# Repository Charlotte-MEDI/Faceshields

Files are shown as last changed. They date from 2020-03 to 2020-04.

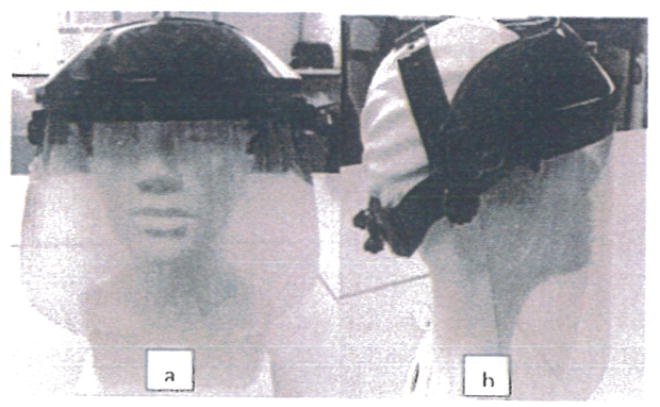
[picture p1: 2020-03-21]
research/cap_facemask.png

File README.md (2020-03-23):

# Faceshields
This repository is to keep track of novel designs of face mask for medical professional to use in critical times

At this time these files are not meant to be mass produced in anyway. As of right now, this is for prototyping different designs.

# March 22nd Print
We are currently printing the Face Shield and can be found in the PrusaFaceShield file.

# Resources:
Prusa Face Shield

https://blog.prusaprinters.org/from-design-to-mass-3d-printing-of-medical-shields-in-three-days/

# Other Designs to think about (May be easier to print?):
 https://www.scmp.com/news/hong-kong/health-environment/article/3052135/polytechnic-university-lab-3d-printing-face
 
 https://www.coxhealth.com/innovation/

# Working Fusion Models:  
-Live Link Prusa Bottom Reinforcement (original, for .5mm thick material) https://a360.co/2UbwLO5  
-Live Link Prusa Bottom Reinforcement (for 1.5mm thick material) https://a360.co/2QEyNnK  
-Believe this one should be a spot on replica, easy to alter the underlying sketches and file if needed  
-Live Link Prusa RC2  https://a360.co/3beMKk8  
-More straight lines in this model, much easier to sketch. Haven't test any prints, but model seems to be correct.  
-Live Link Prusa RC1  https://a360.co/2QAGLOJ

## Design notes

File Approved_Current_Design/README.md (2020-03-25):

# Help us print face shields - The Guide

### What can I do?

We'd love everyone to help!  If you have a 3d Printer, you can print this part:

[Download the 3d Part to Print](https://github.com/Charlotte-MEDI/Faceshields/blob/master/Approved_Current_Design/rc2_headband.stl)  

[Source File](https://www.prusaprinters.org/prints/26474-prusa-rc2-no-elastic-required-secure-with-rope-web)  

### Printer Settings

We want to ensure the printed part is both strong and flexible, our testing shows best results when the part is printed with **100% infill**.  

*Doesn't 100% infill take longer?*  Yes.  Faster, Better, Cheaper... When it comes to protecting our precious medical resources, the medical professionals, our first priority is the best protection.

### How can I package the parts

We want to ensure the printed parts are of the highest quality and does no harm.  

Clean all parts with alcohol (70% or better)
Mark the part with the date, material type (PETG or PLA) and then 
Don't touch the part with your bear hands
	We recommend using alcohol cleaned pliers to handle parts.
	You can use gloves, however, this can be costly.
Place the part in the bag to dry.
Seal the bag once the part is dry.

### Drop Off Locations?

Charlotte Latin FabLab

UNCC

### Additional Notes
These are the original designs from Prusa.  
As of now, these is the most tested, reliable design.  
If you are looking for something to print right away, these are the files for you.  
-The RC2 shield should be printed if your machine is capable.  
-The RC1 shield should by printed if your machine is too small to fit the RC2.  
-The bottom_reinforcement file should fit on any machine.  
-You should include a bottom reinforcement with every headband for a complete kit (minus the clear plastic part)

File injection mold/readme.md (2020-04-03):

This contains all of the design files for the injection molded face shields.

We want to help as many people produce face shields as possible so we’re making all of our files open source and available to everyone.

We started with the Prusa RC2 design and modified it to be injection molding friendly. With the help of Caro-Polymers, we designed a new bottom support that would accommodate PETG sheets of various thicknesses instead of being limited to only 0.02″ thick PETG.

Our design has been validated by doctors and other Health Care Workers in Charlotte, NC using the following materials to manufacture the face shields:

Following materials are used in this design: </br>
Injection molding: FDA approved Polypropylene </br>
PETG sheet: 0.02″ thick PETG (Our feedback from HCWs recommended 0.02″ thick)

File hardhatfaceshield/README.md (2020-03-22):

This face shield was developed by In Hong Yang and Dr. Park at UNC Charlotte.

Made a prototype of a face mask using projector transparency film, ratchet suspension, and hard hat.     
It took 2 minutes to make the prototype.   See the pictures attached.   Parts were glued together.   

https://www.mcmaster.com/5387t78  
Link:  Ratchet Suspension for Vented Hard Hat& Hard Hat with Rain-Trough Brim

https://www.mcmaster.com/5387t78  
Link:  Ratchet Suspension for Vented Hard Hat& Hard Hat with Rain-Trough Brim

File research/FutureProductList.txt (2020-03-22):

valves for ventelators
swabs
Near N95 mask

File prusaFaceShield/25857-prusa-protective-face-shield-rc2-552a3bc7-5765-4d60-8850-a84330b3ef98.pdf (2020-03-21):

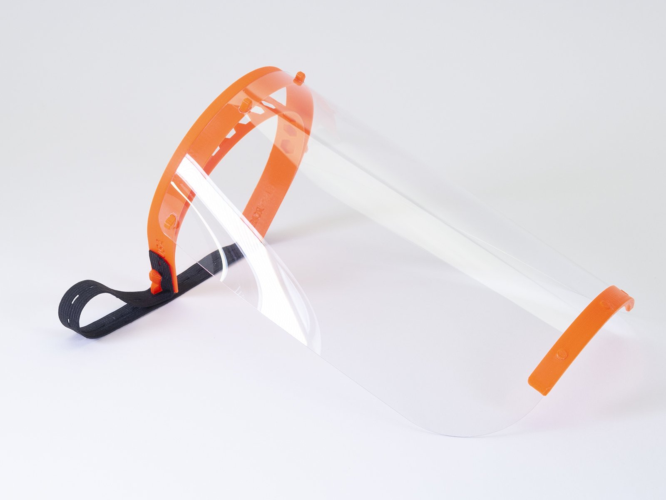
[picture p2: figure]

## Summary

A prototype face shield that we developed. In three days, we went through dozens of prototypes and two verifications with the Czech Ministry of Health.

Version RC2 Changes from RC1:

Increased wall thickness (slightly stiffer and more durable)
Inner wall from 1.5 mm to 2 mm
Outer wall from 2 mm to 2.5 mm
The headband is no longer printed compressed - Lower pressure on the temple
The visor was moved further away from the forehead - This allows a better fit over bigger respirators and protective goggles
The printed part now has an extension for the visor (the visor curves less than the headband).

For now, both RC1 and RC2 versions are relevant. RC1 lets you fit more printed parts on a single print bed. However, if maximum yield isn’t the priority, RC2 provides slightly better protection and is more comfortable to

Prusa Research (https://www.prusaprinters.org/social/16/prints)

## Prusa Protective Face Shield - RC2

VIEW IN BROWSER (https://www.prusaprinters.org/prints/25857-prusa-protective-face-shield-rc2)

updated 20. 3. 2020 | published 20. 3. 2020

•
◦
◦
•

•

•

wear.

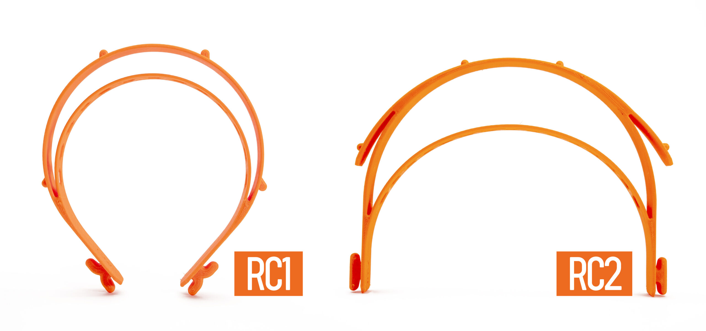
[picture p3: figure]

If you want to manufacture shields for others PLEASE READ THIS CAREFULLY

Act as if you were infected by the COVID-19 virus. Wear a face mask and a fresh pair of gloves when collecting each batch of printed parts. Store the parts immediately in a sealable bag.
Talk with whoever you’re making the shields for, let them know about your manufacturing environment
There is still debate about how long the virus survives on plastic, but most sources mention 2-3 days. That means that by letting the packed face shields sit for 2-3 days before distributing them, you’ll greatly reduce risk of transmission
Do not store the entire stock in one place, minimize the risk of cross contamination

More information: https://blog.prusaprinters.org/from-design-tomass-3d-printing-of-medical-shields-in-three-days/ (https://blog.prusaprinters.org/from-design-to-mass-3d-printing-of-medical-shields-in-three-days/)

Assembly manual: English version (https://manual.prusa3d.com/Guide/Prusa+Face+Shield/1527) English Community version (https://manual.prusa3d.com/Guide/Assembling+the+Prusa+Face+Shield+-+community+version/1528#s41280) Czech version (https://manual.prusa3d.com/Guide/Prusa+Oblicejovy+Stit/1526)

Video:

"https://www.youtube.com/embed/pP7z3iw76GA"

Rubber band You can either use a thicker one and make a hole in it at each end (make at least 10 mm cut) or use a thin one and tie it to both ends of the shield.

Visor / front plate

•

•

•

•

•

2.01 hrs

1 pcs

f

0.25 mm

k

0.40 mm

h

8

32.00 g

d

MK3/S

Print Files (.gcode) | DOWNLOAD ALL FILES (https://www.prusaprinters.org/prints/25857-prusa-protective-face-shield-rc2/files)

4.2 MB

- 2.01 hrs f 0.25 mm k 0.40 mm h PET | 32.20 g d MK3/S
updated 18. 3. 2020 | (https://www.prusaprinters.org/prints/25857-prusa-protective-face-shield-rc2/files)
Model Files (.stl, .3mf, .obj, .amf) | DOWNLOAD ALL FILES (https://www.prusaprinters.org/prints/25857-prusa-protective-face-shield-rc2/files)

284.2 KB
updated 18. 3. 2020 | (https://www.prusaprinters.org/prints/25857-prusa-protective-face-shield-rc2/files)

there is a DXF drawing in the file section (and an alternative longer version)
the holes can be made with a standard office hole puncher
we used 0.5 mm thick petg sheet (Covestro VIVAK), but you should be able to use any clear laser cuttable plastic with similar thickness.

Licence and selling of face shields We share these files under noncommerical licence. It would be great if you donated these shields to those in need for free. If you need to cover your production costs, we are ok with you selling the shields for production cost. However, we do not want to see these shields on eBay for $50.

Healthcare (https://www.prusaprinters.org/prints?categoryId=87) > Accessibility (https://www.prusaprinters.org/prints?categoryId=88)

Supports are not necessary. Print with at least 3 perimeters, about 30% infill.

Ideally, print it from PETG.

•
•

covid19-shield_025mm_petg_mk3s_2h1m.gcode

covid19-shield.3mf

383.1 KB
updated 18. 3. 2020 | (https://www.prusaprinters.org/prints/25857-prusa-protective-face-shield-rc2/files)

52.6 KB
updated 20. 3. 2020 | (https://www.prusaprinters.org/prints/25857-prusa-protective-face-shield-rc2/files)

3.9 KB
updated 18. 3. 2020 | (https://www.prusaprinters.org/prints/25857-prusa-protective-face-shield-rc2/files)

662.6 KB
updated 20. 3. 2020 | (https://www.prusaprinters.org/prints/25857-prusa-protective-face-shield-rc2/files)

585.1 KB
updated 20. 3. 2020 | (https://www.prusaprinters.org/prints/25857-prusa-protective-face-shield-rc2/files)

## License

This work is licensed under a
Creative Commons (4.0 International License)

Attribution-NonCommercial (http://creativecommons.org/licenses/by-nc/4.0/)

✖ | Sharing without ATTRIBUTION
✔ | Remix Culture allowed
✖ | Commercial Use
✖ | Free Cultural Works
✖ | Meets Open Definition

bottom_reinforcement.stl

shield_longer_version.stp

shield_final.dxf

covid19_headband_rc2.stl

covid19_headband_rc1.stl

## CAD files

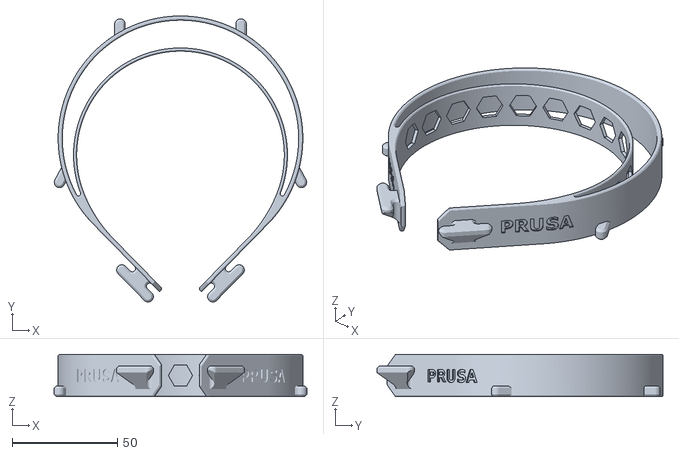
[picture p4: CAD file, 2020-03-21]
Approved_Current_Design/rc1_headband.stl
119.7 x 135.6 x 20.0

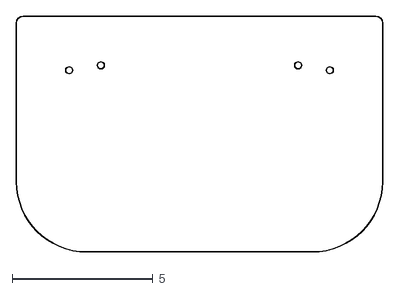
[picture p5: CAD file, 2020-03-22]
cox_health_shield/Face_Shield.dxf
13.0 x 8.38

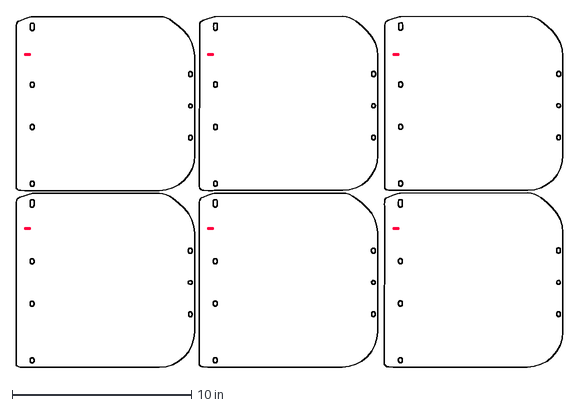
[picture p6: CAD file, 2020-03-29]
final/MEDI_Injection - 2x3.dxf
30.5 x 19.6 in

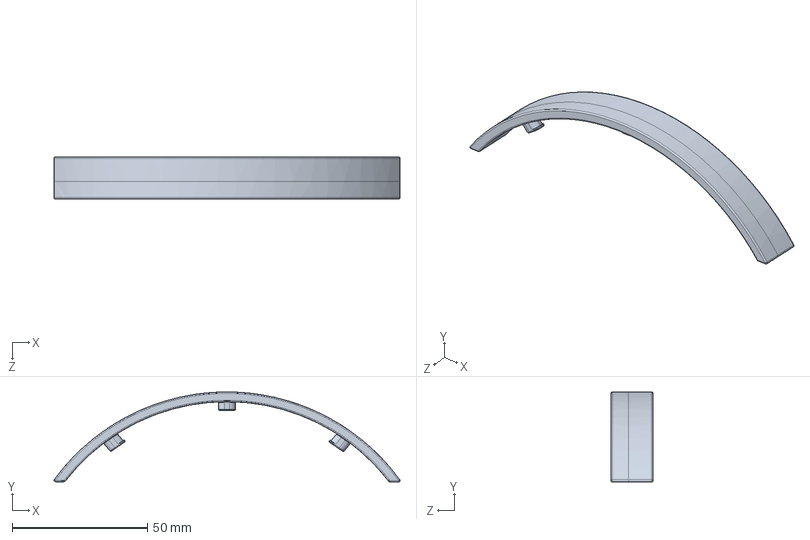
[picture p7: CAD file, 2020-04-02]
injection mold/Bottom support bar.SLDPRT
127.9 x 33.2 x 15.5 mm

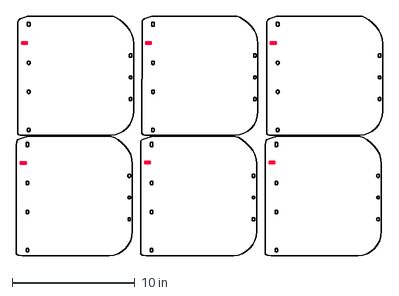
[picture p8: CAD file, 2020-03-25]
prusaFaceShield/shieldDubickModifyCv2 - 2x3.dxf
29.9 x 19.5 in

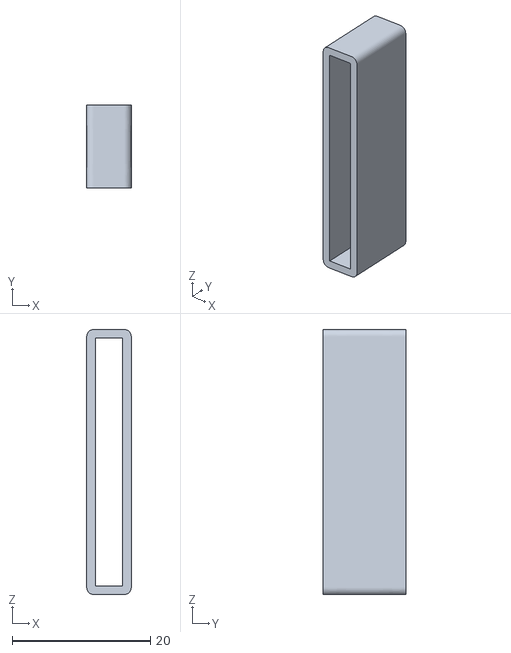
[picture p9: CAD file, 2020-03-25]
StrappedCharlotteFaceShield/StrapHolderClip.stl
6.46 x 12.0 x 38.4

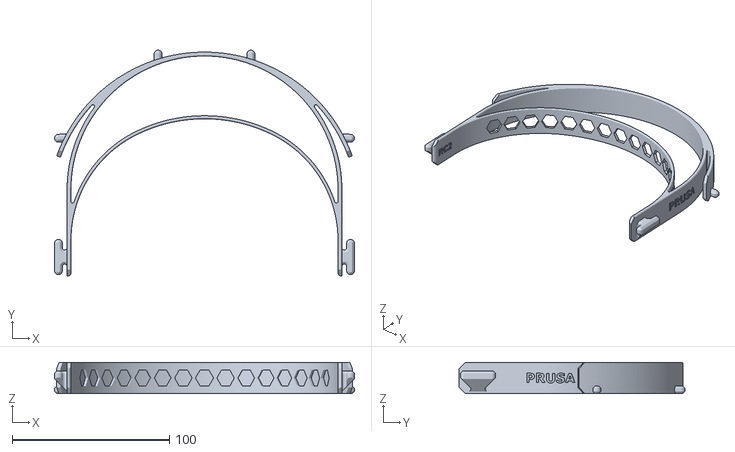
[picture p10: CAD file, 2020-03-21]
Approved_Current_Design/rc2_headband.stl
191.0 x 143.8 x 20.0

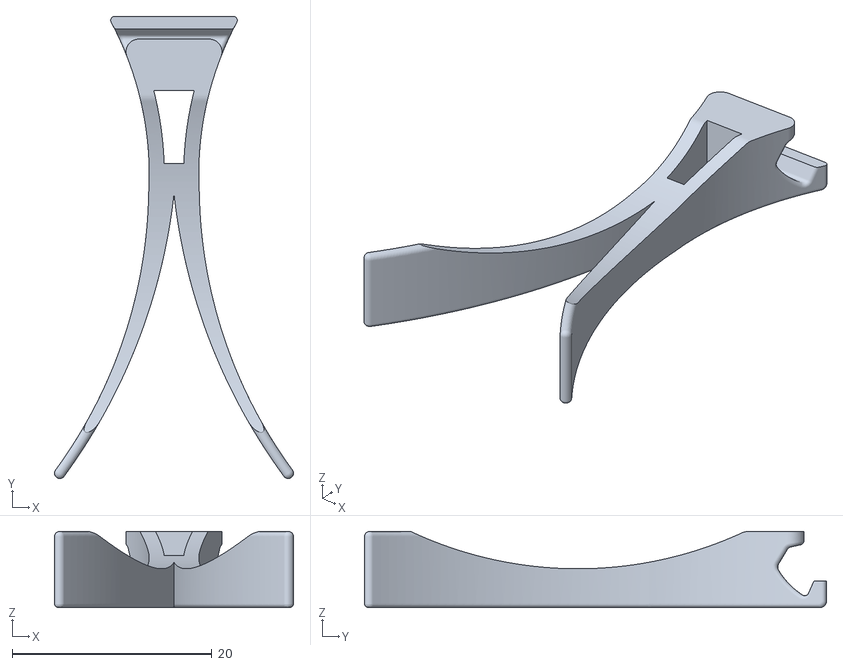
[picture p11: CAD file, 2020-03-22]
cox_health_shield/Nose_Piece_21.stl
23.9 x 46.3 x 7.62

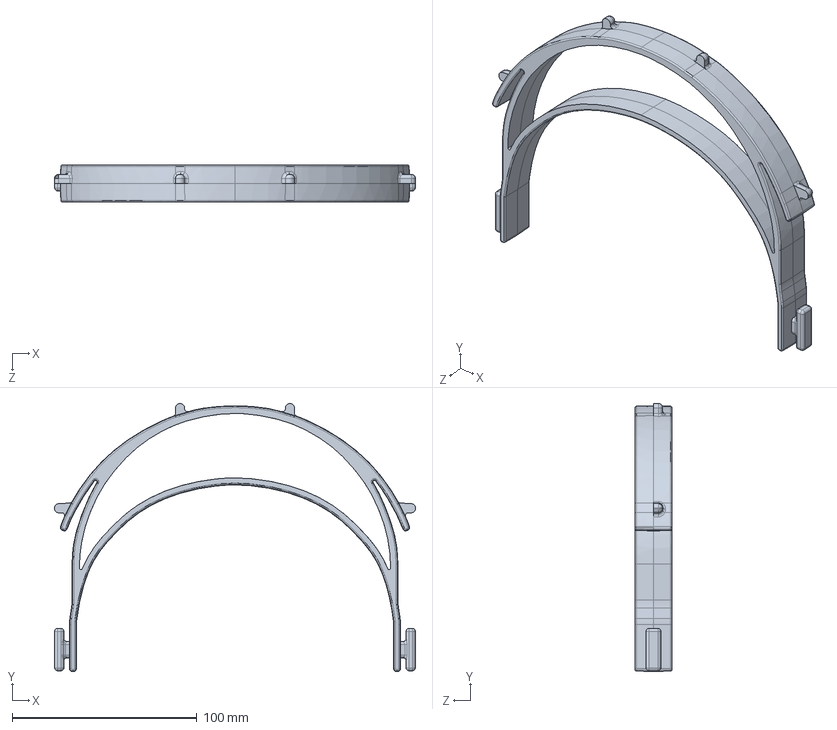
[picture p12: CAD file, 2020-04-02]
injection mold/Headband.STEP
195.3 x 145.0 x 20.0 mm

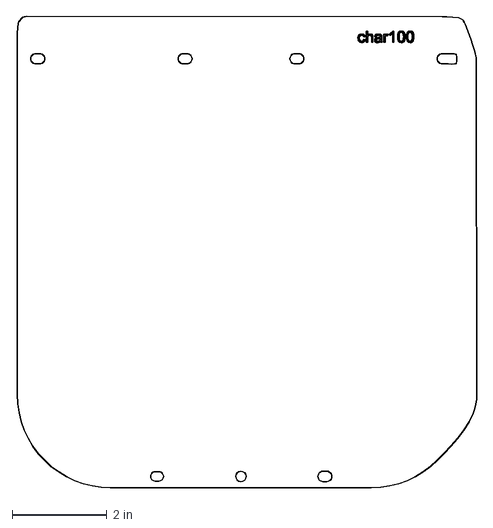
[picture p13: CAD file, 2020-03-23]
prusaFaceShield/shieldDubickModifyB.dxf
9.73 x 9.95 in

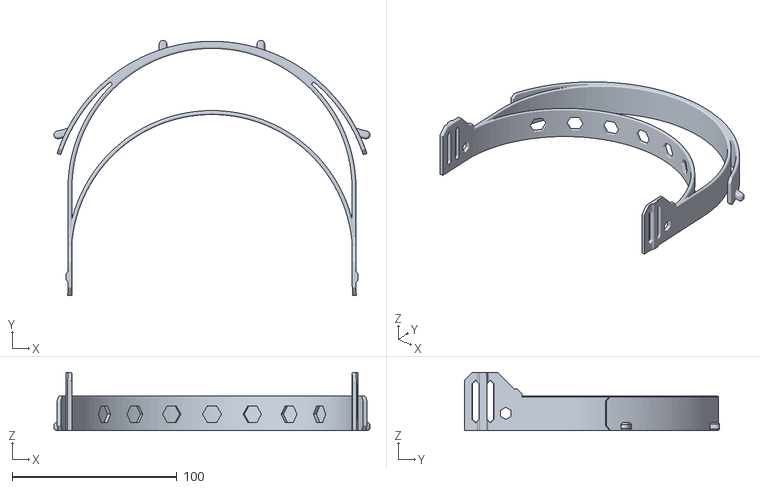
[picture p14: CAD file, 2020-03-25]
StrappedCharlotteFaceShield/strapsriff_rc2_extra_strap_thickness.stl
191.8 x 154.9 x 35.4

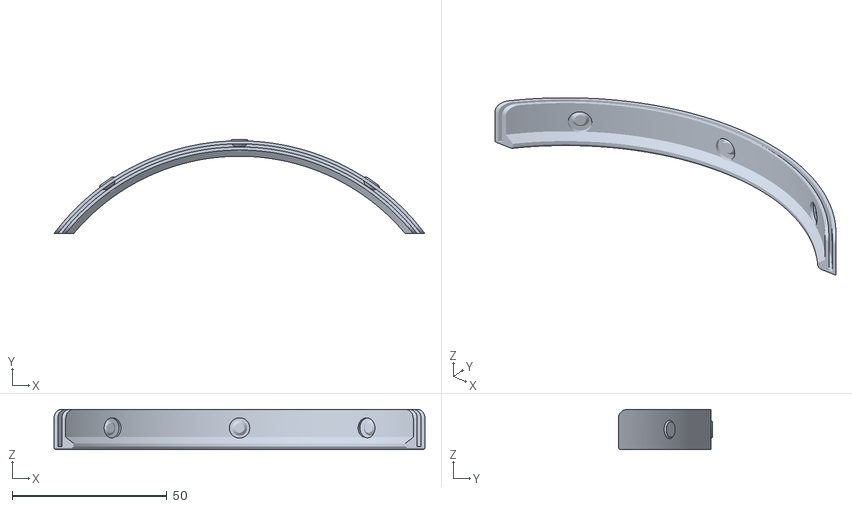
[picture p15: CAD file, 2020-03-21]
Approved_Current_Design/bottom_reinforcement.stl
120.1 x 30.6 x 13.0

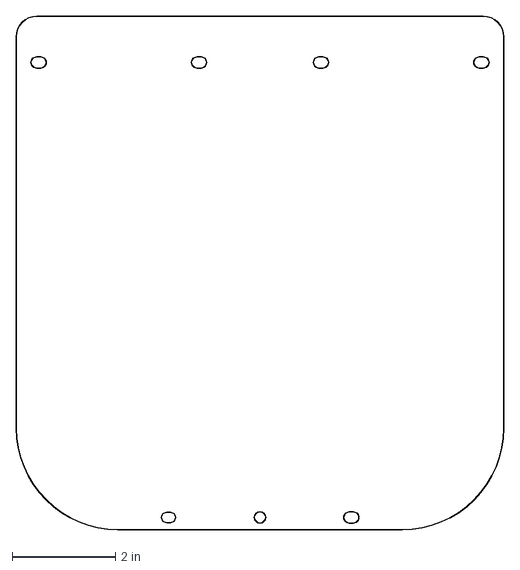
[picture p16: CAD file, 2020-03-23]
prusaFaceShield/FaceShieldExtended.dxf
9.45 x 9.95 in

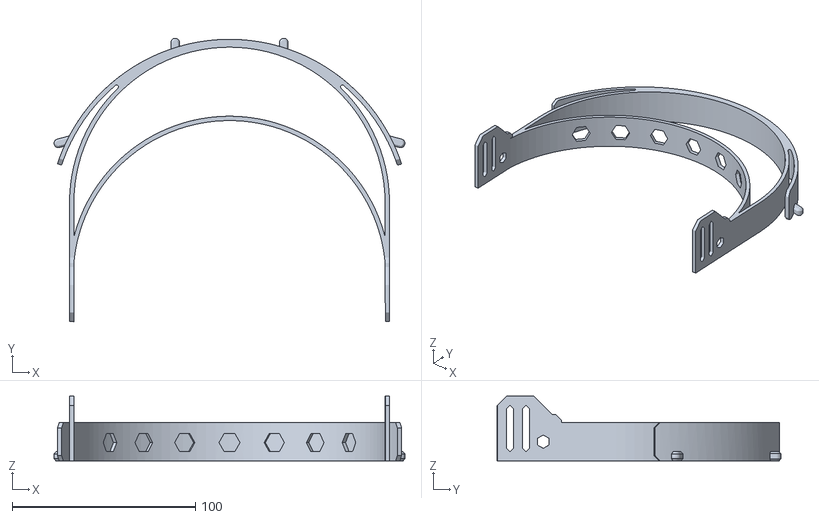
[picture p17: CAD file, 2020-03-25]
StrappedCharlotteFaceShield/strapsriff_rc2.stl
191.8 x 154.9 x 35.4

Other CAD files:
prusaFaceShield/bottom_reinforcement_thickshield.stl
prusaFaceShield/covid19_headband_rc2_2pcs.3mf
prusaFaceShield/covid19_headband_rc2_1pcs.3mf
prusaFaceShield/covid19-shield.3mf
cox_health_shield/Face_Shield.dwg
cox_health_shield/Nose_Piece_21.ipt
prusaFaceShield/shield_final.dxf

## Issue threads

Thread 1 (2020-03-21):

Question of cleaning PETG (clear face shield material we cut with laser or scissors)

thomasd538, 2020-03-21:
IPA, Hydrogen Peroxide, Bleach, and Acetic Acid up to 10% can all be safely used with PETG.

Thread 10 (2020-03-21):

RC2 version improvement over RC1

thomasd538, 2020-03-21:
Folks,
I printed the face shield version RC2.  It appears to move the top of the mask extends out and solves one of the issues broght up by the doctor.

JeremyProffitt, 2020-03-21:
These are the RC1 and RC2 files: https://www.prusaprinters.org/prints/25857-protective-face-shield-rc1/files

JeremyProffitt, 2020-03-21:
It is possible to fit a RC1 and RC2 face shield on a 200x200 print area (the most common print area of a 3d printer).  Just rotate the RC1 face shield 45 degrees, and rotate the bottom pieces, one -15 degrees, one 15 degrees (all rotations are Z axis rotations).  And place as such:
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

My print time for this set is about 5 hours.

thomasd538, 2020-03-21:
Nice job Jeremy.  We will probably need two RC1 for every RC2.

thomasd538, 2020-03-22:
Folks,
Doctors want both R1s and R2s

Tom

danjstone, 2020-03-23:
guys, check out this improvement.....no need to elastic anymore....

https://www.prusaprinters.org/prints/26474-prusa-rc2-no-elastic-required-secure-with-rope-web

dtay1123, 2020-03-23:
Awesome. Should improve time and cost

David C. Taylor

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

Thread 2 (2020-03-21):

The 3d printed material tends to be porous.

thomasd538, 2020-03-21:
1.We need to cover or make the porous the PLA or 3d printed material less porous

JeremyProffitt, 2020-03-21:
My understanding is 3d printed layers achieve better bonding, the higher the layer height, additional head and a small amount of over extrusion may reduce porous-ness.

I'd also be curious about spraying the part, I often use plastidip, basically spray on rubber, on the bottom of prints to add a certain amount of "grip" (keep stuff from moving). Spraying down the part with plastidip would "seal" the plastic and may provide protection.  An ancrylic spray may do the same.

Concerns about spraying a part to reduce the porous nature:
- Adds handling and sitting time which could impact part's safety
- Possible irritation of the skin by the spray
- Volunteer maker concerns
  - volunteer may not know how to effectively spray the part (could we just spray the front?)
  - volunteer may package the part while it's still wet

Are their medically safe spray on solutions?

morrowsend, 2020-03-23:
Jeremy, what resolution are you using for the layer height of your masks currently?

JeremyProffitt, 2020-03-23:
As of this morning, I spoke with one of my 3d printing mentors, who's a
materials engineer working in medical supplies, handy eh?  We agreed, your
layer height should be:

For 0.4 Nozzles - 0.3 mm layer height
For 0.6 Nozzles - 0.45 mm layer height
For 0.8 Nozzles - 0.6 mm layer height.

for others, you typically use the formula 80% of Nozzle Size, i.e. 0.4 x
0.8 = 0.32, then back it down for your printer's accuracy, for example I
can print at 0.05mm accuracy, so I make th at number 3.0

For Infill, it's 100% guys.  Sorry, I know it adds print time, but It will
ensure a stronger mask, remember, these need to be dropable, smackable,
beatable and every other kind of able there is.  I'm looking at different
designs now, anyone with 0.8 nozzles on their machines, let me know, that's
a very different world.

Jeremy

On Mon, Mar 23, 2020 at 11:55 AM morrowsend <notifications@github.com>
wrote:

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

heatherfreeman, 2020-03-23:
Extremely helpful specs, Jeremy, thank you!

morrowsend, 2020-03-23:
Jeremy, are you using supports? On my printer I can't select support only for the outside of the mask, and it fills in all the space-saving holes on the inner ring. The supports are tough to remove even from the outside.

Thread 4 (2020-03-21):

Prevent material from falling down in between the user and the face shield

thomasd538, 2020-03-21:
Next version should be designed to prevent material from falling down in between the user and the face shield

[https://www.gmesupply.com/3m-short-clear-petg-faceshield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](url)
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

morrowsend, 2020-03-23:
We could simply extend the clear part over like an account's green eye shade visor. [Something like this but the curve would be up and over the head instead.](https://en.wikipedia.org/wiki/Green_eyeshade#/media/File:Visorlayout.jpg)

Or we could have them [attach a hair net to the front kind of like this](http://safety.unifirst.com/store/product.cfm?pID=7C51454C48197556)  This method would be a simple tweak of the current design.

morrowsend, 2020-03-23:
I just came across [this different design.](https://web.archive.org/web/20200321115424/https://budmen.com/) The page got the hug of death from being posted by the media so here's the archived version:

JeremyProffitt, 2020-03-23:
i like the idea of needing something over the top to keep splash from
coming back, I think that's important, but that design isn't going to
stretch and be flexible to fit the user's head, so I think we need to focus
on ones that do.

On Mon, Mar 23, 2020 at 11:17 AM morrowsend <notifications@github.com>
wrote:

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

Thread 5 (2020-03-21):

Solution needed for comfort material between front of faceshield printed part and user's head

JeremyProffitt, 2020-03-21:

horvath112, 2020-03-23:
See this design, which utilizes foam tape. Worth noting foam tape is $2 for 10 feet at home depot. Not sure if this could be adapted for the prusa design? https://budmen.com/

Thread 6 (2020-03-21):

Determine life of virus on various surfaces used

stoph, 2020-03-21:

stoph, 2020-03-22:
The current thinking is that it "may persist on surfaces for a few hours or up to several days" [Source](https://www.who.int/news-room/q-a-detail/q-a-coronaviruses)

horvath112, 2020-03-23:
https://www.sciencedaily.com/releases/2020/03/200320192755.htm

"two to three days on plastic"

stoph, 2023-02-23:
We had some good times helping save the world.

thomasd538, 2023-02-23:
Yes, we didSent from my iPhoneOn Feb 23, 2023, at 10:55 AM, Christoph Khouri ***@***.***> wrote:
We had some good times helping save the world.

—Reply to this email directly, view it on GitHub, or unsubscribe.You are receiving this because you are subscribed to this thread.Message ID: ***@***.***>

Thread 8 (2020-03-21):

Vacuum Molding the Shield?

dtay1123, 2020-03-21:
Could we vacuum mold the shield and head covering parts? After speaking with Terence and Alex from UNCC, an MDF component would need to be milled out for support and there would be some post-processing of the parts. We could use an actual shield with a head covering from the doctors as the mold. This could possible fix the issue of the size, angle, and head covering concerns. Alex has a vacuum molding tool in his lab at UNCC.
I got the idea from talking with Tom and watching these videos about making a vacuum mold for customs/masks: https://youtu.be/Gx66mS7U2vY , https://www.youtube.com/watch?v=Cox8fR1rUBI , and https://mods-n-hacks.gadgethacks.com/how-to/make-your-own-halloween-masks-by-modding-your-shop-vac-into-vacuum-forming-machine-0139413/.

Thoughts? This is just an idea.

JeremyProffitt, 2020-03-21:
Part of the functionality of this design is the ability for the face shield to become wider and skinnier based on the user's head size, I am curious how we retain that capability on a vacuum formed part, especially given the top will be a 1/4 sphere.

If we can address that concern, perhaps indenting the area around the for head while adding 1/4 spheres at the top and bottom of the shield would allow not only for the face shield to stick out some from the forehead, but also allow us to add just some padding to the indented area and straps on either side, removing the requirement for the 3d printed part.  Kinda like this, but perhaps like this:

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

dtay1123, 2020-03-21:
Great point! Could we possibly hole punch and use your component for attachment? This could keep the user flexibility.

JeremyProffitt, 2020-03-21:
If the plastic is soft enough when at room temp, I wonder if it wouldn't stretch.  Heck, we could make a big and small version too.  But this is not something all people can do, but the time to make is extremely fast and we could trim with a hot knife.

dtay1123, 2020-03-21:
That's a good point. I feel that the front load of the work will take the longest. Alex stated he thinks it would take about 5 minutes to produce the parts. I feel that having the advantage of heat gives us a lot of flexibility.

JeremyProffitt, 2020-03-21:
I can likely 3d print a model, that model could be used on a cnc to generate the model to use with a vacuum form machine.

dtay1123, 2020-03-22:
Sounds good!

tjfagan, 2020-03-22:
I was emailing back and forth one of the professors at UNCC, the one who wrote the book on manufacturing. Any, thermoforming may be used in the long run for batches. I asked him if he knew any local companies.

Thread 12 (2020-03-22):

Mobilizing those who want to help?  Collect info starting now?

JeremyProffitt, 2020-03-22:
I've been getting people asking me how they can help, for now, I'm directing them to go fund me, did we want to make an online web page to collect contact information, area of expertise (use check boxes?), equipment available?  Location?  Then perhaps targeted emails to like people with lasers or 3d printers, etc?

Thoughts on this:

Name:
Email:
Phone:
ZipCode:

Support Effort Areas you can assist in?

3d Printing
Laser Cutting
Assembly
Marketing/Strategy
Medical
Doctor?  Nurse?  Executive?
Materials/Manufacturing

Number of 3d Printers
Number of Laser Cutters

dtay1123, 2020-03-22:
This is a great idea. This can help organize people. The addresses can be put into google maps to create a list showing where everyone is located visually. Should we add "materials" people have available already?

tjfagan, 2020-03-22:
I agree, we can work out who is going to be the point person for this in the next meeting.

fireroad602, 2020-03-23:
Hey! This is Anna Chai. I'm managing the GoFundMe. I am happy to help w. this 👍

I'm making a master Contacts List of everyone involved, which will help populate a Google Map.

And -- there is an existing Google Map that lists Industrial 3D Printing Services:
https://www.google.com/maps/d/u/0/viewer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

I would like to reach out to the providers in / around CLT, to see if they want to join CLT_MEDI -- but first, I would like to make a "Getting Started Kit," complete w. a list of materials, sanitizing practices, etc.

thomasd538, 2020-03-23:
Great idea

Sent from my iPhone

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

JeremyProffitt, 2020-03-23:
Yep, I'm working today on the 3d printing instructions and video, generic so we can use it for other parts if need be as well

fireroad602, 2020-03-23:
Thx!! We also need:

- instructions on disinfecting and sanitizing.

- the modified design files, which Tom is working on.

- a list of materials including quantities ... Shd we also list vendors / sources to purchase?

fireroad602, 2020-03-23:
I'm adding the new CLT_MEDI social handles to the GoFundMe and will include info about people who want to volunteer and/or get involved and start 3D printing themselves.

To minimize hand holding, Tom suggested that we vet community makers to people who have a minimum of 5 3D printers. I think this is reasonable.

I set up cls.makers@gmail.com as a generic e-mail for the GoFundMe but @stoph -- were you able to get up CLT_MEDI@gmail.com ... I'd rather have consistency across all communications.

fireroad602, 2020-03-23:
Here is the Contact Sheet I started:  https://docs.google.com/spreadsheets/d/165wMwc149RoFIN8_P0QmmomMubuxA5kasyIaaXJE9Fs/edit?usp=sharing

I have been adding notes about offers to help and notes on where we stand w. them. This is editable, so please feel free to add.

fireroad602, 2020-03-23:
@JeremyProffitt

Should we be using this?
3D Printer Crowdsourcing for COVID-19
https://docs.google.com/spreadsheets/u/1/d/1QE1vzezYdf6QJwxaMMLrWIks5AYAPUeSRWXxaYd3yK8/htmlview?sle=true

The Google Sheet is populated by and provides a link to this Submission Form:
https://docs.google.com/forms/d/e/1FAIpQLSdVfWaQi31l8VNUY6CVctJm5bElMmBKL7YG3mHY8ASvvcwrag/viewform

And they provide Open Source COVID-19 Medical Supplies Guide
https://docs.google.com/document/d/1-71FJTmI1Q1kjSDLP0EegMERjg_0kk_7UfaRE4r66Mg/preview

This might be a good way to add and assess new partners?

majyamber, 2021-01-27:
Yep! This is good idea everybody must conceive and participate guys

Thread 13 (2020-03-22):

Medical Staff Survey  - feedback for the face shields

thomasd538, 2020-03-22:
Folks,
We need to create a quick survey for medical personnel so we can get feedback on the face shields.
What do we think of the four following questions?   Please make suggestions.

Did the faces shield work as intended?
yes
not
If not, why not.

Did the face shield break while you were using it?
yes
no
If so, what happen?

How comfortable is the mask?
1 to 10  (1 - painful)  (10 - comfortable)

Do you have any suggestions?

JeremyProffitt, 2020-03-22:
Looks good, platform?  Survey Monkey?  Perhaps we print out slips of paper with a short url to use to get to the survey as well?

dtay1123, 2020-03-22:
Google form is easy and free. Also, it opens into a spreadsheet with data charts.

JeremyProffitt, 2020-03-22:
That sounds great!

Should we add what version 1 or 2 they prefer?

On Sun, Mar 22, 2020, 12:01 PM David Taylor <notifications@github.com>
wrote:

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

stoph, 2020-03-22:
When are we going to ask these questions? Seems like am initial questionnaire when they get the masks (first impressions) then a follow-up survey a few days later to see how they are holding up/if anything broke.

Also, can we expect to get feedback directly from the users, or should we try to get a point of contact within each group (head nurse, etc) to solicit feedback for us?

thomasd538, 2020-03-22:
I  was hoping to have the nurses fill out survey Monday night after using the facemaks for aday.

Our point of contact  right now is Jean and Julie Chai who are both doctors and help start this

thomasd538, 2020-03-22:
Good suggestion on asking about the version they like.  I will also update shield so they can identify if they are using 1 or 2.

dtay1123, 2020-03-22:
Tom, did you start a survey or do you want me to begin working on it?

dtay1123, 2020-03-22:
https://docs.google.com/forms/d/1f1yQcWOaGO_e_ZMt9W13Po1ughF1EaBVwzVy3lqsi9k/edit?usp=sharing

The link above is to a survey I just created.

JeremyProffitt, 2020-03-22:
We should maybe have them share pictures of what does not work??

On Sun, Mar 22, 2020, 12:54 PM David Taylor <notifications@github.com>
wrote:

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

dtay1123, 2020-03-22:
I can see if that is an option. I do like this idea, Jeremy.

dtay1123, 2020-03-22:
Jeremy, You can have people attach images, but you have to have a gmail account. What do you think?

dtay1123, 2020-03-22:
[`Feedback Survey`](https://docs.google.com/forms/d/1f1yQcWOaGO_e_ZMt9W13Po1ughF1EaBVwzVy3lqsi9k/edit?usp=sharing)

tjfagan, 2020-03-23:
I am going to close this issue because there is two threads, follow the below link for the new thread.

https://github.com/tjfagan/Faceshields/issues/19

Closed 2020-03-23.

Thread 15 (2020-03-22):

Makers - please disinfect

thomasd538, 2020-03-22:
Folks,

What do you think of the following?
Please wipe everything  down that you  with bleach, rubbing alcohol or disinfectant.  Put in plastic bag or garbage bag so we we can hand over to the hospital.  Clear bags with your name , phone number quantity and type products.

JeremyProffitt, 2020-03-22:
I'm putting mine in these, one top, one bottom, one bag.

https://www.amazon.com/gp/product/B073X32N5J/ref=ox_sc_saved_title_2?smid=A1B40VJ62843EO&psc=1

I'm thinking we should tell them to throw away the wipe away every so often, like every few hours?  Or clean in batches.

I staged what I printed last night in these, 2.5 gallon bags:

https://www.amazon.com/gp/product/B000E0XX96/ref=ox_sc_saved_title_1?smid=A2Q1LRYTXHYQ2K&psc=1

I'm concerned if we don't have paper on the plastic, we'll need to keep it separate from the 3d print as it's likely to scratch it, or deliver a package of tops and bottoms bagged, and a stack of shields?

dtay1123, 2020-03-22:
You put parts in smaller bags inside of a larger bag.

heatherfreeman, 2020-03-22:
Re: Disinfecting, I made a disinfectant bath (undiluted Lysol) and put them in one set at a time (to not crowd) for several minutes. Then washed/sanitized my hands again (we're out of gloves), rinsed them in very hot water, dried them sandwiched between new paper towels, and then placed them in clear plastic bags (I'll run out of the clear bags soon, will figure something out).

I'm not keen on this process: my hands are involved too much and I don't trust 'em.

Curious to hear others' workflows for this.

dtay1123, 2020-03-23:
I wore a N-95 mask while disinfecting my components to limit possible airborne pathogens. I clean the area I had with bleach before setting the components on to it. I used a pair of tongs that I disinfected ahead of time to cut down on my hands touching. I only had bleach available for cleaning the parts. I then labeled the parts and put them in fresh ziplock bags.

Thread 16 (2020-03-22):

Folk we can use more RC1

thomasd538, 2020-03-22:
Initial feedback from doctors say the RC1 seem to fit woman better.  Plus, RC1 can be made on all smaller printers.

dtay1123, 2020-03-22:
I am printing the rc1 all day.

heatherfreeman, 2020-03-22:
Once this last one finishes, I'll start on RC1s

tjfagan, 2020-03-23:
Is this still an issue?

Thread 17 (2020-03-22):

Branding Name - or what are people going to call us?

thomasd538, 2020-03-22:
As Jamie pointed out, we need some kind of branding or at very least a name:
here are some suggestions

Charlotte MEDI - (Medical emergency Device Innovators)

Charlotte MPG innovators (medical protective gear)

What do you think?  Any ideas?

thomasd538, 2020-03-22:
we are now Charlotte MEDI

Closed 2020-03-22.

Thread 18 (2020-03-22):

Please label your prints as PLA or PETG

thomasd538, 2020-03-22:
Folks please write PLA Or PETG next to R1 Or R2 with  permanent marker on the head band portion of the FaceMask.   This will help track material performance

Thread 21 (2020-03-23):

Is anyone looking at at the Cox Health Design?

tjfagan, 2020-03-23:
We should look at this design, the print I believe is drastically reduced. Keep in mind if the time is cut, also the print material is cut, therefore more Shields can be produced. It appears many more.

JeremyProffitt, 2020-03-23:
I took another look, they are using the frame part of a pair of safety glasses, hoping someone has one in their shop we can look at, if we 3d model it, it could be mass produced rather quickly.  We could even possibly look at using plastic rod and heat forming them around a mold?

https://www.medexsupply.com/infection-control-protective-apparel-protective-eyewear-kimberly-clark-safeview-safety-assembled-glasses-50-cs-x_pid-74374.html

Here is the un-assembled version for half the price:
https://www.medexsupply.com/infection-control-protective-apparel-protective-eyewear-medline-safety-assembled-glasses-50-cs-x_pid-89368.html

Then we just print the nose piece, and likely use a piece or rubber at the end?  or?

I'm also wondering how well this would do against the skin on the nose piece (3m's rubber tape, 0.76mm thick)
https://www.3m.com/3M/en_US/company-us/all-3m-products/~/Scotch-Rubber-Splicing-Tape-23/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

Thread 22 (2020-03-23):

Marketing needs (Site, Social Media, etc)

stoph, 2020-03-23:
Registered CharlotteMEDI.com and CharlotteMEDI.org. Will set up a site using GitHub Pages (Free)

Twitter, Facebook, and Instagram "CharlotteMEDI" names are taken (as well as Charlotte_MEDI)

Turns out there is also a weight loss clinic in Charlotte called Medi

dtay1123, 2020-03-23:
@stoph thanks for looking into that information. Bummer about the weight lose group.

thomasd538, 2020-03-23:
Fagan just suggested CharlotteMEDIOrganization.  I like CharlotteMEDIPandemic  - You need a little dark humor.

thomasd538, 2020-03-23:
Seriously, how about MEDICLT is that avialable on twitter, facebook, etc?

stoph, 2020-03-23:
Sorry, too slow to update this thread. I created CLT_MEDI on all platforms.

fireroad602, 2020-03-23:
Perfect!

dtay1123, 2020-03-23:
@stoph i like the CLT_MEDI. it connects with the website url and projects the same name. Nice work! Also CLT is a popular handle for Charlotte now. Great work!

stoph, 2020-03-23:
https://www.facebook.com/Charlotte-Medi-100811044905278/ (Will fix that username later)
https://twitter.com/CLT_MEDI
https://www.instagram.com/clt_medi/

About to create the github page as well. @tjfagan thoughts on moving this out of your personal space into a 'Charlotte MEDI' org?

JeremyProffitt, 2020-03-23:
should we bind the social media sites with ifttt so postings on twitter or instagram automatically post everywhere else?

stoph, 2020-03-23:
I've recruited a buddy that does marketing/social media for a living to help out. Josh Tessler. I'll ask him to maybe join a call in a couple days to talk through some options.

tjfagan, 2020-03-23:
@stoph please feel free to get the items off my personal site.

I do want to continue to research and develop not on the CHarlotteMEDI and have a few people so the public does not get confused as to where to start.

fireroad602, 2020-03-24:
@stoph Can I get login info for Instagram clt_medi?

My sister in law is sending me photos, videos, and testimonials from the clinicians who are using the face shields?

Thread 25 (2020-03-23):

No-print face shield design?  Do we want to explore?

JeremyProffitt, 2020-03-23:
https://www.delve.com/insights/face-shield-designs-to-fill-the-gap

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

danjstone, 2020-03-23:
Great design/idea, can significalty ramp up production throughput.

I think we should explore furthur but I have not experince with foam and adhisves to know how hard this would vs. 3D print.

tjfagan, 2020-03-23:
We should build a couple to see if this will even hold up under medical scrutiny.

dtay1123, 2020-03-23:
I think this is a good idea to explore ramping up amounts being made. It would be good to check with a doctor on using this model.

thomasd538, 2020-03-23:
As mention by someone, I think we need to create a group for vetting new idea using predetermine criteria.

dtay1123, 2020-03-23:
@thomasd538 it would be nice to have a consistent group to run through

JeremyProffitt, 2020-03-23:
Design review wed and sat?  Can we a doctor on with that?

On Mon, Mar 23, 2020, 11:12 AM David Taylor <notifications@github.com>
wrote:

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

danjstone, 2020-03-24:
who is leading the new product group?

1. I have aligned 2 doctors that are willing to jump in and help - want to get them looped in

2. Check this out this ventilator
https://futurism.com/neoscope/3d-printed-adapter-snorkelling-mask-into-ventilator

tjfagan, 2020-03-25:
Dan,

I just got this, did you get an answer. I will post on slack.

Best regards,
Terence

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

--
Terence J Fagan, Ph.D.
"It is not the critic who counts: not the man who points out how the strong
man stumbles or where the doer of deeds could have done better. The credit
belongs to the man who is actually in the arena, whose face is marred by
dust and sweat and blood, who strives valiantly, who errs and comes up
short again and again, because there is no effort without error or
shortcoming, but who knows the great enthusiasms, the great devotions, who
spends himself for a worthy cause; who, at the best, knows, in the end, the
triumph of high achievement, and who, at the worst, if he fails, at least
he fails while daring greatly, so that his place shall never be with those
cold and timid souls who knew neither victory nor defeat."

"Citizenship in a Republic,"
Speech at the Sorbonne, Paris, April 23, 1910

tjfagan, 2020-03-25:
Now that I looked at it. My buddy just sent me a link to this.

Best Regards,

Terence

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

--
Terence J Fagan, Ph.D.
"It is not the critic who counts: not the man who points out how the strong
man stumbles or where the doer of deeds could have done better. The credit
belongs to the man who is actually in the arena, whose face is marred by
dust and sweat and blood, who strives valiantly, who errs and comes up
short again and again, because there is no effort without error or
shortcoming, but who knows the great enthusiasms, the great devotions, who
spends himself for a worthy cause; who, at the best, knows, in the end, the
triumph of high achievement, and who, at the worst, if he fails, at least
he fails while daring greatly, so that his place shall never be with those
cold and timid souls who knew neither victory nor defeat."

"Citizenship in a Republic,"
Speech at the Sorbonne, Paris, April 23, 1910

danjstone, 2020-03-25:
Thanks Terence Sent from my Samsung Galaxy smartphone.
-------- Original message --------From: Terence <notifications@github.com> Date: 3/24/20  9:01 PM  (GMT-05:00) To: Charlotte-MEDI/Faceshields <Faceshields@noreply.github.com> Cc: danjstone <dan@909street.com>, Comment <comment@noreply.github.com> Subject: Re: [Charlotte-MEDI/Faceshields] No-print face shield design?  Do we want to explore? (#25)

Dan,

I just got this, did you get an answer. I will post on slack.

Best regards,

Terence

On Tue, Mar 24, 2020 at 12:47 PM danjstone <notifications@github.com> wrote:

> who is leading the new product group?

>

>    1.

>

>    I have aligned 2 doctors that are willing to jump in and help - want

>    to get them looped in

>    2.

>

>    Check this out this ventilator

>

>    https://futurism.com/neoscope/3d-printed-adapter-snorkelling-mask-into-ventilator

>

> —

> You are receiving this because you commented.

> Reply to this email directly, view it on GitHub

> <https://github.com/Charlotte-MEDI/Faceshields/issues/25#issuecomment-603360335>,

> or unsubscribe

> <https://github.com/notifications/unsubscribe-auth/ABTQJ26DCETJRL6DWNO7I3LRJDP2HANCNFSM4LRZXD3Q>

> .

>

--

Terence J Fagan, Ph.D.

"It is not the critic who counts: not the man who points out how the strong

man stumbles or where the doer of deeds could have done better. The credit

belongs to the man who is actually in the arena, whose face is marred by

dust and sweat and blood, who strives valiantly, who errs and comes up

short again and again, because there is no effort without error or

shortcoming, but who knows the great enthusiasms, the great devotions, who

spends himself for a worthy cause; who, at the best, knows, in the end, the

triumph of high achievement, and who, at the worst, if he fails, at least

he fails while daring greatly, so that his place shall never be with those

cold and timid souls who knew neither victory nor defeat."

"Citizenship in a Republic,"

Speech at the Sorbonne, Paris, April 23, 1910

—You are receiving this because you commented.Reply to this email directly, view it on GitHub, or unsubscribe.

[

{

"@context": "http://schema.org",

"@type": "EmailMessage",

"potentialAction": {

"@type": "ViewAction",

"target": "https://github.com/Charlotte-MEDI/Faceshields/issues/25#issuecomment-603582217",

"url": "https://github.com/Charlotte-MEDI/Faceshields/issues/25#issuecomment-603582217",

"name": "View Issue"

},

"description": "View this Issue on GitHub",

"publisher": {

"@type": "Organization",

"name": "GitHub",

"url": "https://github.com"

}

}

]

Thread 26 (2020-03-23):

Production volume - maker community 2 week target ?

danjstone, 2020-03-23:
Hi Guys,

I wanted to get a discussion on our production volume forecast/demand.

I assume we have aprox 1 week to 10 days before moving around will get locked down significalntly which will slow us down significantly.

As we lock in on a design and start to plan and buy matareials it is parcticaly impossible to do so with out some type of volume forecast/target.

Lots of factor goes into how long it will take us to manufacture (design/number of printers/mataerials/number of lasers/people hours etc).

We can do the "best we can" but are likley to either overpurchase or end up with the wrong mix of supplies.

We have plastic for 10K face shelids but current deisgn time to 3D print we are unlikley to be able to  manufacture 10K in 2 weeks.

Are we ready to set a production target for us as a maker community for the next 2 week?

ds

tjfagan, 2020-03-23:
I agree, I was just about to put this question out there. I am lining up manufactures who are willing and able to help, The volume amount would be a good piece of information.

We have access to a company who can make 1000 face shields (transparent piece)/day out of PVC. Also, we need a medical professional interface so we can ask these types of questions. I will put this in another issue.

thomasd538, 2020-03-23:
Also, I am getting several more makers this morning offering to help print.  I do agree we need to get this to industry as possible, we can ramp up to 50 -100 masks a day.   Not enough, but it helps until we can industry involved

dtay1123, 2020-03-23:
Pros and Cons of casting a wider net for makers?

JeremyProffitt, 2020-03-23:
Con:
  More people making, the more chances of infecting medical staff?
  more quality control is required
  more attention needed for managing makers, dedicated person?
Pros:
  Higher quantities, the only way to hit 1000 in a week?
  More test cases to test different print materials/type

stoph, 2020-03-23:
I agree we need more folks involved to hit those numbers, but we also have to balance peoples want to help and their ability. My concern is that anyone with a 3D printer would _want_ to help, but we could quickly get into a situation were our experts (i.e. Jeremy) are spending too much time helping people debug print issues. Even if it's just asking people to rate themselves on a scale of 1-5 and only take the 3+'s (for now)

Secondly, with more makers, logistics becomes an issues delivering and picking up prints. It might make more sense to have 10 makers who can produce 10 each rather than 100 who can produce 1 each.

What are some other areas they could help besides printing?

heatherfreeman, 2020-03-23:
I'm a little biased (as a person with one hacker printer) but I'd strongly recommend keeping this open to the larger community. For functional reasons, it makes sense to have a community point person (not Jeremy!), although ideally, they have enough knowledge to help trouble-shoot.

There are a couple reasons (some cited above):

1) There may come a point when, even with industrial production, community help is needed. (I can't stop thinking of all my WWII studies in this regard!). It's worth the trouble to nurture that part of the community now, since if we _do_ get to a point where demand exceeds industry supply, it will be much harder to coordinate later.  Right now, there's a lot of goodwill -- it's important to channel that somehow, even if that doesn't feed directly into designs used for industrial manufacture.

2) If people come to this group wanting to help, and the group turns them away, it will foster some frustration and add to the overall sense of helplessness -- even hopelessness.  What's the single most important thing each of us can do right now? Wash our hands and stay home!  But we're social animals -- our human natures are at their best when we're most altruistic.  I know this may seem like a very minor concern, but I'm telling you right now -- those who serve the public *mental* health are also being stretched.  We need to help medical professionals holistically.

I'd recommend running the industry output numbers by the docs and state public health admin.
 If they see the public help as more harm then good, well, there you go then.  But I think it's really worth assigning a point person (graduate students? advanced undergrads?) to help be the smaller community outreach and point person.    It may ultimately make more sense to actually split that group off entirely, but I think keeping a clear line of communication open is important.

Anyway, just my thoughts on this, but I respect and appreciate whatever the rest of the group decides.

stoph, 2020-03-23:
100% agree Heather. Sorry, I didn't mean to say we'd turn _anyone_ away, just want to make sure we have a process in place to handle the volunteers and someone dedicated to that effort. I just spoke with someone coordinating volunteers to help assemble too and there were a lot of questions I didn't have answers to **yet**.

heatherfreeman, 2020-03-23:
Sorry, myself, hope I didn't sound crabby, just one of those home-school+online-class+printer-fails kind of days. :D

I *do* think this would be a great thing for a grad student to take over (we don't have any in Art, but Alex might know some?)

Tasks would/could include
- Creating a PDF of specs for different machine types
- PDF (with images) of how to disinfect, bag, and label
- Pickup-delivery coordination with other volunteers without printers
- Organizing sub-groups of volunteers by type - those who can lasercut, those who can print, those who can run masks -- and if/when N95s run out, those who can sew surgical masks, gowns, etc. (That's another branch of inquiry, but no doubt relevant to the whole unless there's a tested and reliable N95 DIY design eventually.)

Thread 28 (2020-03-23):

User-tweaked designs on Prusa's website

morrowsend, 2020-03-23:
Has anyone tried these?
[This design](https://www.prusaprinters.org/prints/26474-prusa-rc2-no-elastic-required-secure-with-rope-web) uses either string or webbing (think tie-down strap material conference bag handles) instead of elastic.  He mentions an elastic shortage (never heard of such a thing).

There's also[ this slightly modified version of the masks ](https://www.prusaprinters.org/prints/26507-prusa-protective-shield-remix-for-vase-mode-printi)that uses "Vase Mode" and uses about 1/4th the plastic. Should be faster to print.

You can see all the remixes by scrolling down [this page](https://www.prusaprinters.org/prints/25857-protective-face-shield-rc1/remixes).

Thoughts?

JeremyProffitt, 2020-03-23:
I've started printing some of those.  The vase mode one scares me for strength, but am trying it.

JeremyProffitt, 2020-03-23:
I have samples of these printing now

https://www.prusaprinters.org/prints/26077-prusa-medical-face-shield-lite
https://www.prusaprinters.org/prints/26474-prusa-rc2-no-elastic-required-secure-with-rope-web
https://www.prusaprinters.org/prints/26507-prusa-protective-shield-remix-for-vase-mode-printi

danjstone, 2020-03-23:
Thanks Jeremy! Looking forward to hearing if we should move over to any of these

tjfagan, 2020-03-23:
Does this change the transparent peice?

JeremyProffitt, 2020-03-24:
No, however, if a volunteer's printer isn't properly calibrated, they could be printing the piece just enough off the part doesn't fit, it's an issue we've seen.

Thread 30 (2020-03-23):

Materials

fireroad602, 2020-03-23:
@thomasd538 @tjfagan

Request from Jim Olsen @ Atrium Health -- He needs to know what type of material you are using in the clear shield.

Let me know and I'll communicate? Thx!

tjfagan, 2020-03-23:
Thank you, I am looking at producing the transparent piece using PVC. Hope this helps. Please let me know if you have any other questions.

tjfagan, 2020-03-23:
Currently, we are using PETG, however, I have a manufacture that can make roughly 1000/hour. This is tremendously more volume than we are producing now.

fireroad602, 2020-03-24:
Copy. Will share w. Atrium Health. Thx!!

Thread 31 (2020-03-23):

Materials Purchase update - 3/23 - 3pm

danjstone, 2020-03-23:
Guys,

Quick update after our call:

1. elastic band - Scott already connect with elastic supplier and they are looking for 10K feet in the Charlotte area.  They said it is getting harder to move product around right now.

waiting for update on availability and price
2. Filament - we are reaching out to https://www.fiberich-usa.com/  the company in Mooresville that jeremy recommended. Please post on this thread any other.

for 10K mask we need 800lbs of filament. For now we are trying to get 200lbs PLA and 200lbs PETG. that should get us a lot of the way there if we include people own inventory.

Once we have a final decision on PLA vs. PETG we can go ahead and try to purchase the rest of the amount.

3. Shipping / billing address - for right now we are planning to ask delivery if available to Charlotte Latin School - Fab Lab. We are also asking them to send bills to the same address.

Tom Dubik
Fab Lab
Charlotte Latin School
9502 Providence Rd, Charlotte, NC 28277

Let us know if this is incorrect

Please list any link or other sources / contact that we can work with as suppliers

Thanks,
Dan

fireroad602, 2020-03-23:
@danjstone

Re: elastic, I found 1000 yards of 1-inch elastic that can be overnighted from Mauldin, SC but it was NOT Button Elastic. So, Tom told me not to pursue.

Re: clear plastic material, I know that PETGClear is being delivered by Piedmont Plastics. The Infection Prevention (IP) Dept @ Atrium Health needs more info about that clear plastic material to see if it is OK by CDC standards. Can you send me info ASAP?

Thx

danjstone, 2020-03-23:
ok, will chase down with piedmont plastics. I do not know much about plastics. Do we know what specs to ask for?

Also, have secured about 200lbs of PETG and 200lbs of PLA in moorsville - need transportation - they will hold it for us until Thursday.

fireroad602, 2020-03-23:
Thank You!

I found this on Piedmont Plastics website. Is this what we purchased?
https://www.piedmontplastics.com/products/petg

If so, it seems like PP could confirm:
- Thickness / Gauge
- Which "industry leading suppliers including Plaskolite, Inc., Primex Plastics, and PolyOne™" provided the order we just received?

@thomasd538 Did we get any sort of invoice / bill? That might help also.

danjstone, 2020-03-23:
Talked PP they are emailing spec to me and Tom. Will post as soon as I get it

fireroad602, 2020-03-23:
Amazing. Thx!

sgardner9015, 2020-03-23:
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

Guys, a quick update.
I was able to place a hold on product today, here is where we are;
Company; Jinos 3D
Contact RG
Phone Number'; 704=907-9649
Address; 142 Lugnut Lane, Mooresville, NC 28117
   - 1,75 mm PLA, 200lbs @ $12 per roll (2,2 lbs each)
   - 1.75 mm PETG 200lbs @ $14.49 per roll
The order will need to be picked up and paid for by close of business Thursday. That is as long as they will hold it.  They will be producing the last 150 lbs of the PETG this week, the rest they have in stock.

On the buttonhole elastic, I spoke to Gifford DelGrande of AEC Narrow Fabrics today, he is working on our requirement and I am awaiting a return call.  If I don't hear back by mid morning I will follow up with him.

Thanks,
Scott

fireroad602, 2020-03-24:
I was introduced to people in Bulk Sales @ Joann.

JeremyProffitt, 2020-03-24:
You looking to buy approximately 90 rolls of PETG and 90 rolls of PLA?  I'm running 15 printers, 50g per part, each part takes 3 hours, so I use about 8-12 pounds a day, depending how many times I get up at night to start new prints.  Maybe try to buy half that if possible?  I have enough PETG for the week and a month's worth of PLA I'm happy to use up for this project, I got it cheap and rarely print with it.

danjstone, 2020-03-24:
Thanks Jeremy, we put in the order and now need to arrange for pick today or latest tomorrow.

Will check if we can change quantity,  worst case the fab lab students will have enough filaments for their projects next year :)

ds

danjstone, 2020-03-24:
@fireroad602 Got the detail spec from Piedmont - just sent to you via email

danjstone, 2020-03-24:
Priority for today is to get truck to pick up 400lbs of filament from Moorsville and arrange for payment

If someone can help please contact Scott @sgardner9015 to get detail (Scott Gardner <sgardner9015@gmail.com> / +1 919 434 8836)

fireroad602, 2020-03-24:
Can I purchase the 1000 yards of 1-inch elastic from Rubies Costume? They are based in Mauldin, SC but if he sends UPS, it will arrive tomorrow.

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

danjstone, 2020-03-24:
@fireroad602 do you know if the 1 inch fit into the new RC2 model with the adjustable strap slots??

If yes, I think it may be good to purchase

@sgardner9015 did we get an answer from the button elastic provider?

fireroad602, 2020-03-24:
@danjstone This is what they used last night. So I will go ahead and purchase.

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

danjstone, 2020-03-24:
GreatSent from my Samsung Galaxy smartphone.
-------- Original message --------From: fireroad602 <notifications@github.com> Date: 3/24/20  10:51 AM  (GMT-05:00) To: Charlotte-MEDI/Faceshields <Faceshields@noreply.github.com> Cc: danjstone <dan@909street.com>, Mention <mention@noreply.github.com> Subject: Re: [Charlotte-MEDI/Faceshields] Materials Purchase update - 3/23 - 3pm (#31)
@danjstone This is what they used last night. So I will go ahead and purchase.

—You are receiving this because you were mentioned.Reply to this email directly, view it on GitHub, or unsubscribe.
[
{
"@context": "http://schema.org",
"@type": "EmailMessage",
"potentialAction": {
"@type": "ViewAction",
"target": "https://github.com/Charlotte-MEDI/Faceshields/issues/31#issuecomment-603284446",
"url": "https://github.com/Charlotte-MEDI/Faceshields/issues/31#issuecomment-603284446",
"name": "View Issue"
},
"description": "View this Issue on GitHub",
"publisher": {
"@type": "Organization",
"name": "GitHub",
"url": "https://github.com"
}
}
]

fireroad602, 2020-03-24:
Even better, I got the 1000 yards of elastic for free and it will arrive tomorrow!

danjstone, 2020-03-24:
Sweet!! Sent from my Samsung Galaxy smartphone.
-------- Original message --------From: fireroad602 <notifications@github.com> Date: 3/24/20  10:58 AM  (GMT-05:00) To: Charlotte-MEDI/Faceshields <Faceshields@noreply.github.com> Cc: danjstone <dan@909street.com>, Mention <mention@noreply.github.com> Subject: Re: [Charlotte-MEDI/Faceshields] Materials Purchase update - 3/23 - 3pm (#31)
Even better, I got the 1000 yards of elastic for free and it will arrive tomorrow!

—You are receiving this because you were mentioned.Reply to this email directly, view it on GitHub, or unsubscribe.
[
{
"@context": "http://schema.org",
"@type": "EmailMessage",
"potentialAction": {
"@type": "ViewAction",
"target": "https://github.com/Charlotte-MEDI/Faceshields/issues/31#issuecomment-603288559",
"url": "https://github.com/Charlotte-MEDI/Faceshields/issues/31#issuecomment-603288559",
"name": "View Issue"
},
"description": "View this Issue on GitHub",
"publisher": {
"@type": "Organization",
"name": "GitHub",
"url": "https://github.com"
}
}
]

fireroad602, 2020-03-24:
Budmen designs has set up a channel for pre-cut plastic.

We have received many requests for where to buy the clear plastic material, we have been coordinating with PaperGala to make pre-cut and hole punched sheets available. They are now ready for order.
· To help as many healthcare workers as possible: Please do not over buy. We do not want inventory tied up, Paper Gala will be continuously producing so please order only what you can use immediately.
· Please contact the healthcare providers you are working with to ensure that PET-G meets their needs.
Purchase pre-cut 10-packs of PETG poly sheets here:
https://papergala.com/

Does this help us get to assembly faster?

dtay1123, 2020-03-24:
I cut 137 straps last night. Ill drop them off at the lab this evening with my prints.

Sent from my iPad

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

thomasd538, 2020-03-24:
You sir are the man

On Tue, Mar 24, 2020 at 11:31 AM David Taylor <notifications@github.com>
wrote:

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

fireroad602, 2020-03-24:
@danjstone @thomasd538 I have a volunteer w. an SUV who can go pick up the Filament in Mooresville.

fireroad602, 2020-03-24:
In case it's helpful, one of our local partners used this ingenious trick for the elastic:

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

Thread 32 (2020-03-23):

Injection Molding parts

morrowsend, 2020-03-23:
I'm talking with a local plastic injection molding company. They have laser cutters, CNC tooling and injection molding machines. They recommended some design changes for manufacturability. I'm not sure if I can post the pics he sent me online for open viewing (they are from another product he produce's CAD files.  But I'm sending them to you Terence.

tjfagan, 2020-03-23:
Welcome aboard, please send them my way, I am in talks with multi companies to do some engineering and manufacturing for the shields. Great job!

JeremyProffitt, 2020-03-23:
Can you send me a picture too?  What is the lead time?

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

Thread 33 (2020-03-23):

EMT and First Responders

heatherfreeman, 2020-03-23:
I got word from a friend who used to be a Cabarrus county first responder that they're totally going without protective gear already (hospitals are generally getting first preference).  I imagine this is true for Mecklenberg County as well.

If we already have a direct contact with Meck County Emergency Services, we can close this Issue number. Otherwise I can reach out to them and get a contact over there. Those medical workers are definitely a population that is at very high risk.

Along those lines, somebody from Atrium pulmonary group called me today - they were already out by the time I got a chance to call them, but I'll try again tomorrow.

tjfagan, 2020-03-23:
Wow, thanks for letting us know. I have a nurse friend who was asked to wear bandanas today for PPE. That really shows the state are HCP are in.

On a similar note, there is a number floating around NC Health Care system needs appr. 40k/ month. Injection molding won't be up and running for a little while. So we need to help all HCP

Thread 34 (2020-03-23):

Cheapest, fastest, and easiest Face Shield (Cost me only pennies)

morrowsend, 2020-03-23:
After my 3d printer failed midway through both versions of the Prusa prints, I determined there's a much easier way to build these facemasks and much cheaper and faster as well. I modeled it after a commercial facemask with stuff I had in my garage. I used Plastic hanging tape (polypropylene) some pop rivets and while I didn't have the correct type of plastic, I had a good stand-in material. If we use 11x17 laminator pouches this design costs a few cents each. I documented here with text and video:
http://sheekgeek.org/2020/adamsheekgeek/cheapest-and-fastest-covid-19-face-shield

tjfagan, 2020-03-23:
Nice job!

JeremyProffitt, 2020-03-24:
I'm wondering the same if we used strips of PETG, say two on the front, two behind it a bit, just like the 3d printed part, if we could attach everything.  I'm trying to figure out fastening, rivits, even when used from the inside, would leave the inside okay, but have a fair bit of stub sticking out that could catch something.  It's in the right direction though, for sure.

heatherfreeman, 2020-03-24:
This is great -- Jeremy, if I can scrounge those materials around the house, I may play around with it. Duct tape be a simply Macgyver on that problem.

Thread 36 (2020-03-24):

Website Wireframe

heatherfreeman, 2020-03-24:
I'm going to conscript some former students/current colleagues to work on a website, primarily a wireframe of info.  I'm doing a lot of synchronous teaching today (meetings with students, basically), but I'll try to pull together a basic layout before the end of the day.  Primary categories I see right now are

1. What we are doing > Sub > Overview, Media, Contact Info
2. For Community Organizations > Maker spaces, Non Profits, Schools > $ Donations , Volunteers, Outreach, partnerships, Resources for those out of NC
3. For Industry and Corporate Organizations > Material donations, $ donations, Engineering questions, Partnerships, Resources for those out of NC
4. For Medical Professionals > Getting equipment, PPE suggestions, Medical device suggestions, other resources, Resources for those out of NC
5. For Individuals > $ donations, volunteers (individual makers, runners, support), CDC and WHO links, Resources for those out of NC
6. For Makers > Files, Instructions, Sterilization Instructions, Drop off/pick up instructions, additional resources

The list above is a mess (obviously), but please post additional info categories that should be on the website, and I'll get this better organized with my colleagues.

Finally, each major category should probably have a hierarchy of point people so that it doesn't all fall on Terence, Jeremy, etc. :) I'm speaking with some friends who have experience with that sort of stuff, but once we have an information flow sorted out, non-maker volunteers could be critical in helping information flow smoothly.

heatherfreeman, 2020-03-24:
Copying and pasting from the Slack volunteer needs/opportunities:
My thoughts: Social media likes, follows, shares. Pickup and delivery drivers. Video and photo editor. Organizer of contact lists. Supply/Procurement help. Marketing help.
Do we need an accountant for the GoFundMe account?
We have community outreach? Research and Design? Design to manufacturing? 3D printing for your local community?

heatherfreeman, 2020-03-24:
FYI, Bobby Campbell (UNCC Graphic Design professor) says he'll help with the website. I'll talk with him this afternoon.

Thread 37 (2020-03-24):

Moving the Maker meeting to 5:00 PM

thomasd538, 2020-03-24:
Folks,

Dr. Fagan is right now investigating injection molding and our face masks.   We can go from 100 to 100 masks a day.   We need to move the meeting to five.   I also think 5 pm helps avoid the work interruptions.  Please share...

Tom

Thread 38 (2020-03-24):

Additional design to convert scuba masks to work with ventilator via 3D print

morrowsend, 2020-03-24:
[Here's yet another great design in which a small 3D printed part can help](https://futurism.com/neoscope/3d-printed-adapter-snorkelling-mask-into-ventilator) Apparently [the actual files are attached on this forum](https://www.3dprintingmedia.network/forums/topic/charlotte-valve-by-isinnova-for-non-invasive-ventilator/) from the company.

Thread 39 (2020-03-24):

HP posted free medical 3D print files

danjstone, 2020-03-24:
https://enable.hp.com/us-en-3dprint-COVID-19-containment-applications

morrowsend, 2020-03-25:
These are neat, I think the door handle attachment is a great idea for after the crisis dies down.

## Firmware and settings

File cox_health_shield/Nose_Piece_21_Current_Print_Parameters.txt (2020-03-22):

;   profileName,ABS-Taz5- 0.4mm 
;   profileVersion,2020-03-19 17:03:10

;   printMaterial,ABS

;   extruderDiameter,0.4
;   extruderAutoWidth,1
;   extruderWidth,0.48
;   extrusionMultiplier,0.95
;   extruderUseRetract,1
;   extruderRetractionDistance,1
;   extruderExtraRestartDistance,0
;   extruderRetractionZLift,0
;   extruderRetractionSpeed,1602
;   extruderUseCoasting,1
;   extruderCoastingDistance,0.1
;   extruderUseWipe,1
;   extruderWipeDistance,0.1
; 
;   layerHeight,0.25
;   topSolidLayers,5
;   bottomSolidLayers,4
;   perimeterOutlines,2
;   printPerimetersInsideOut,1

;   startPointOptio

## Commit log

2020-03-21 files to create face shield
    [bottom_reinforcement.stl, covid19_headband_rc1.stl, covid19_headband_rc2.stl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]
2020-03-22 Files from cox Health
    [Face_Shield.dwg, Face_Shield.dxf, Nose_Piece_21.ipt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]
2020-03-22 Add files via upload
    These are new improved face shield files. The shield covers much of the 3d printed materials and I have included an identical mark (chars100) we can track in field.
    [shieldDubickModifyB.dxf]
2020-03-22 Created files in the prusaFaceShield
    Archive orginial Prusa Face shield
    [bottom_reinforcement.stl, covid19-shield.3mf, covid19_headband_rc1.stl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]
2020-03-23 moved to PrusaFaceShield
    [bottom_reinforcement.stl, covid19_headband_rc1.stl, covid19_headband_rc2.stl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]
2020-03-23 Added STL file for 1.5mm shield material
    The thicker shield puts a little more stress on the parts, but everything still seems to be holding together okay.
    [bottom_reinforcement_thickshield.stl]
2020-03-23 Adding Extended Face Shield DXF
    adds .5" of height to the top of the face shield profile
    hole pattern unaltered
    [FaceShieldExtended.dxf]
2020-03-23 Moved Files
    [shieldDubickModifyB.dxf]
2020-03-24 Initial Commit of printable file.
    [strapsriff_rc2.stl]
2020-03-24 Added STL with extra thickness for strap support
    [strapsriff_rc2_extra_strap_thickness.stl]
2020-03-25 Newest Visor files
    [shieldDubickModifyCv2 - 2x3.dxf]
2020-03-25 Clip to help hold elastic in place.
    Should be slid over the "arm" of the face shield before the elastic is put through, then slid back to secure the elastic
    [StrapHolderClip.stl]
2020-03-25 Changed Folder Name for Stapped Version
    [StrapHolderClip.stl, strapsriff_rc2.stl, strapsriff_rc2_extra_strap_thickness.stl]
2020-03-25 Added Approved Current Design Folder
    [bottom_reinforcement.stl, covid19_headband_rc1.stl, covid19_headband_rc2.stl]
2020-03-25 Created Readme
    tried to include clear instructions here about which prints to print
2020-03-25 Cleaned up file names
    [rc1_headband.stl, rc2_headband.stl]
2020-03-29 Current Visor files
2020-03-29 Injection molded visor
    [MEDI_Injection - 2x3.dxf]
